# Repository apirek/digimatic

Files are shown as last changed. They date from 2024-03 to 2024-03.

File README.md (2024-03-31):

# Digimatic USB-Adaptor
Read out Mitutoyo measuring instruments via USB.

Tested with ID-SX2 indicator.

## Usage
The adaptor presents itself as a serial device to the computer.
Any input (e.g. newline) requests a measurement.
The measured value is output as a decimal number with `.` (dot) separator in the unit of measurement of the instrument, followed by a newline.
Errors are reported on lines starting with `#` (hash).

## Wiring
A wiring diagram can be found [here](schematics/Digimatic%20USB%20Adaptor.pdf).

The DATA and CK signals are connected directly to GPIOs.
The REQ signal is switched to ground with a NPN transistor.

The connector of the Digimatic data cables fits Molex 70246 series or 2.54 mm headers.
Looking at the connector of the cable face-on with the key up, pos. 1 is top left and pos. 2 is below, bottom left.

## Build
The Pico C SDK and TinyUSB are required and included as Git submodules.
Git submodules may need to be initialized after a clone:
```sh
git submodule update --init --recursive
```

Build with CMake:
```sh
mkdir src/build
cd src/build
cmake ..
make

## Flash binary by copying via USB
# cp digimatic.uf2 ~/media/RPI-RP2
## OR flash binary with OpenOCD
# openocd -f interface/cmsis-dap.cfg -f target/rp2040.cfg -c "adapter speed 5000" -c "program digimatic.elf verify reset exit"
```

## References
* https://forum.arduino.cc/t/mitutoyo-digimatic-spc/78312 and https://github.com/Roger-random/mitutoyo for a general understanding of the protocol and interface.
* Mitutoyo manual no. 99MAH059D1 for technical description and connector pinout.

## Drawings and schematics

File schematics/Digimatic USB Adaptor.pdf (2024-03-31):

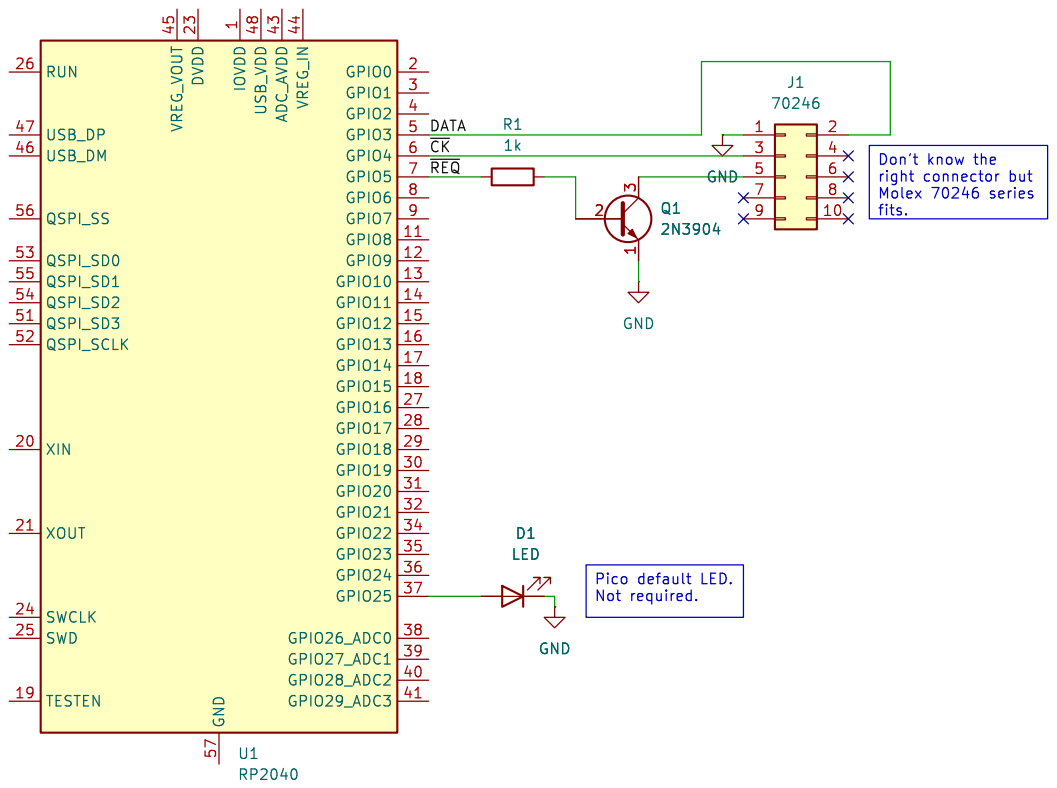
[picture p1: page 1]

1 GPIO8 11 GPIO9 12 GPIO10 13 GPIO11 14 GPIO12 15 GPIO13 16 GPIO14 17 GPIO15 18 TESTEN 19 GPIO0 2 XIN 20 XOUT 21 DVDD 23 SWCLK 24 SWD 25 RUN 26 GPIO16 27 GPIO17 28 GPIO18 29 GPIO1 3 GPIO19 30 GPIO20 31 GPIO21 32 GPIO22 34 GPIO23 35 GPIO24 36 GPIO25 37 GPIO26_ADC0 38 GPIO27_ADC1 39 GPIO2 4 GPIO28_ADC2 40 GPIO29_ADC3 41 ADC_AVDD 43 VREG_IN 44 VREG_VOUT 45 USB_DM 46 USB_DP 47 USB_VDD 48 GPIO3 5 QSPI_SD3 51 QSPI_SCLK 52 QSPI_SD0 53 QSPI_SD2 54 QSPI_SD1 55 QSPI_SS 56 GND 57 GPIO4 6 GPIO5 7 GPIO6 8 GPIO7 9 U1 RP2040

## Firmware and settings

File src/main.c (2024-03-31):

/*
  Digimatic USB
  Copyright (C) 2024 Axel Pirek

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
  This program is distributed in the hope that it will be useful, but WITHOUT ANY WARRANTY;
  without even the implied warranty of MERCHANTABILITY or FITNESS FOR A PARTICULAR PURPOSE.
  See the GNU General Public License for more details.

  You should have received a copy of the GNU General Public License along with this program.
  If not, see <https://www.gnu.org/licenses/>.
*/

#include <stdio.h>

#include "hardware/gpio.h"
#include "pico/stdio.h"
#include "pico/stdlib.h"

#include "digimatic.h"
#include "led.h"

#define DIGIMATIC_PIN_DATA 3
#define DIGIMATIC_PIN_CK 4
#define DIGIMATIC_PIN_REQ 5

#define LED_PIN 25

int main() {
  stdio_init_all();

#ifdef LED_PIN
  struct led_data act_led;
  led_init(&act_led, LED_PIN);
  led_enable(&act_led, true);
#endif

  struct digimatic_data digimatic;
  digimatic_init(&digimatic, DIGIMATIC_PIN_CK, DIGIMATIC_PIN_DATA, DIGIMATIC_PIN_REQ);

  double value;
  int c, r;
  while (true) {
    // Trigger on any input.
    if ((c = getchar_timeout_us(-1)) != PICO_ERROR_TIMEOUT) {
#ifdef LED_PIN
      led_enable(&act_led, false);
#endif

      if ((r = digimatic_read(&digimatic, &value)) < 0) {
        printf("# Error reading from instrument: %d\n", r);
      } else {
        printf("%f\n", value);
      }

#ifdef LED_PIN
      led_enable(&act_led, true);
#endif
    }
  }
}

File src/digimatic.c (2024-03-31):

/*
  Digimatic USB
  Copyright (C) 2024 Axel Pirek

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
  This program is distributed in the hope that it will be useful, but WITHOUT ANY WARRANTY;
  without even the implied warranty of MERCHANTABILITY or FITNESS FOR A PARTICULAR PURPOSE.
  See the GNU General Public License for more details.

  You should have received a copy of the GNU General Public License along with this program.
  If not, see <https://www.gnu.org/licenses/>.
*/

#include <string.h>

#include "hardware/gpio.h"
#include "pico/time.h"

#include "digimatic.h"

void digimatic_init(struct digimatic_data* data, const uint pin_ck, const uint pin_data, const uint pin_req) {
  data->pin_ck = pin_ck;
  data->pin_data = pin_data;
  data->pin_req = pin_req;
  memset(data->buffer, 0, sizeof(data->buffer));
  data->len = 0;

  gpio_init(data->pin_ck);
  gpio_pull_up(data->pin_ck);

  gpio_init(data->pin_data);
  gpio_pull_up(data->pin_data);

  gpio_init(data->pin_req);
  gpio_set_dir(data->pin_req, GPIO_OUT);
  gpio_put(data->pin_req, 1);
  // Invert if REQ is connected via transistor.
  gpio_set_outover(data->pin_req, GPIO_OVERRIDE_INVERT);
}

int digimatic_parse_buffer(const uint8_t* buffer, const size_t len, double* value, enum digimatic_unit* unit) {
  // Check buffer length.
  if (len < 13) {
    return -1;
  }
  // First 4 nibbles are 0xF, ignore.
  // Parse sign.
  int sign = 0;
  switch (buffer[4]) {
    case 0x00:
      sign = 1;
      break;
    case 0x08:
      sign = -1;
      break;
    default:
      // Bad sign.
      return -1;
  }
  // Parse decimal point.
  int div = 0;
  switch (buffer[11]) {
    case 0x02:
      div = 100;
      break;
    case 0x03:
      div = 1000;
      break;
    case 0x04:
      div = 10000;
      break;
    case 0x05:
      div = 100000;
      break;
    default:
      // Bad decimal point.
      return -1;
  }
  // Parse value.
  if (value != NULL) {
    *value = (double) ((uint32_t) buffer[5] * 100000
        + buffer[6] * 10000
        + buffer[7] * 1000
        + buffer[8] * 100
        + buffer[9] * 10
        + buffer[10]
      ) / div * sign;
  }
  // Parse unit.
  if (unit != NULL) {
    switch (buffer[12]) {
      case 0x00:
        *unit = DIGIMATIC_UNIT_MM;
        break;
      case 0x01:
        *unit = DIGIMATIC_UNIT_IN;
        break;
      default:
        // Bad value for unit.
        return -1;
    }
  }
  return 0;
}

int digimatic_read_bit(struct digimatic_data* data, uint8_t* value) {
  // Timeout when no clock after (T2 + T3 + T4) seconds.
  const uint64_t now = time_us_64();
  const uint64_t timeout = now + 540;
  // Wait for CK to be high.
  while (time_us_64() <= timeout) {
    if (gpio_get(data->pin_ck)) {
      break;
    }
  }
  // Wait for CK to go low.
  while (time_us_64() <= timeout) {
    if (!gpio_get(data->pin_ck)) {
      *value = gpio_get(data->pin_data);
      return 0;
    }
  }
  return -1;
}

int digimatic_read(struct digimatic_data* data, double* value) {
  // Clear buffer.
  memset(data->buffer, 0, sizeof(data->buffer));
  data->len = 0;

  // Pull down REQ.
  gpio_put(data->pin_req, 0);

  // Read data.
  size_t i = 0;
  uint8_t bit = 0;
  // Timeout when no data after T1 seconds.
  const uint64_t now = time_us_64();
  const uint64_t timeout = now + 937500;
  while (!i && time_us_64() <= timeout) {
    // Read until clock timeout.
    while (digimatic_read_bit(data, &bit) >= 0) {
      // Release REQ.
      gpio_put(data->pin_req, 1);
      // Check bounds.
      if (i >= sizeof(data->buffer) * 8) {
        return -2;
      }
      data->buffer[i / 4] |= (bit << (i % 4));
      ++i;
    }
  }
  // Timeout, no data.
  if (!i) {
    return -1;
  }
  // Parse data.
  data->len = i / 4 + (i % 4 != 0);
  return digimatic_parse_buffer(data->buffer, data->len, value, NULL);
}

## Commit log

2024-03-31 Add schematics
    [Digimatic USB Adaptor.kicad_sch]
2024-03-31 Blink LED on activity
    [Digimatic USB Adaptor.kicad_sch]
2024-03-31 Describe wiring in readme
2024-03-31 Mention device this was developed with

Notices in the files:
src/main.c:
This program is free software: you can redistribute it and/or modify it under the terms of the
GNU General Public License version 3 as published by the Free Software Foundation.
